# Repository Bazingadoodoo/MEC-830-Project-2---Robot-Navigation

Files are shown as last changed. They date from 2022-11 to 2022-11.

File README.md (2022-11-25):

# MEC-830-Project-2---Robot-Navigation

Group Member 

 - Nillan Nimal
 - Mohammed Khan
 - Cheng-Hao(Howard), Kao

 Arduino Board

 - pin 2: encoder left
 - pin 3: encoder right
 - pin 4: ultrasonic trig pin 
 - pin 5: ultrasonic echo pin
 - pin 6: servo signal pin (pwm) => X
 - pin 7: IR receiver pin => 11
 - pin 8: motor driver in3 => 7
 - pin 9: motor driver in4 => 8
 - pin 10: motor driver enB (pwm) => 6
 - pin 11: motor driver enA (pwm) => 9
 - pin 12: motor driver in1
 - pin 13: motor driver in2

enA: right wheel, in1, in2//
enB: left wheel, in3, in4//
caster wheel diameter: 2.56cm//
rubber wheel radius: 6.65cm//
distance = (impulses/20)*10.4558cm//

remote buttons:
-23971  25245   -7651
8925    765     -15811
-8161   -22441  -28561
26775   -26521  -20401 
12495   6375    31365
4335    14535   23205
17085   19125   21165

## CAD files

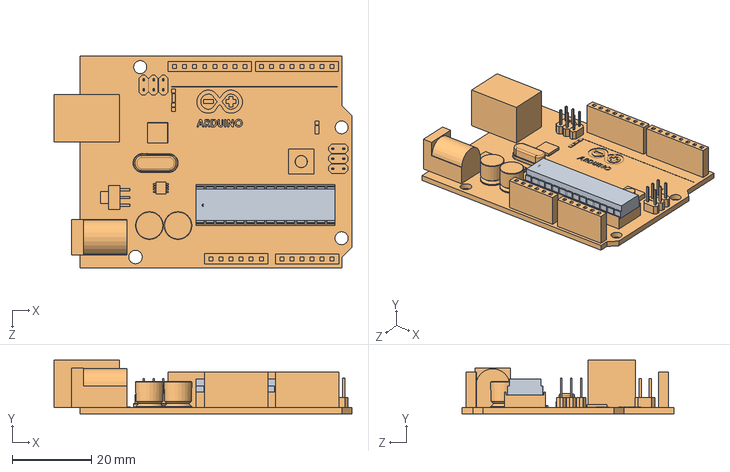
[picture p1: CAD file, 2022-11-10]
CAD Files/Arduino.SLDASM
75.1 x 13.6 x 53.5 mm
atmel
ARDUINO

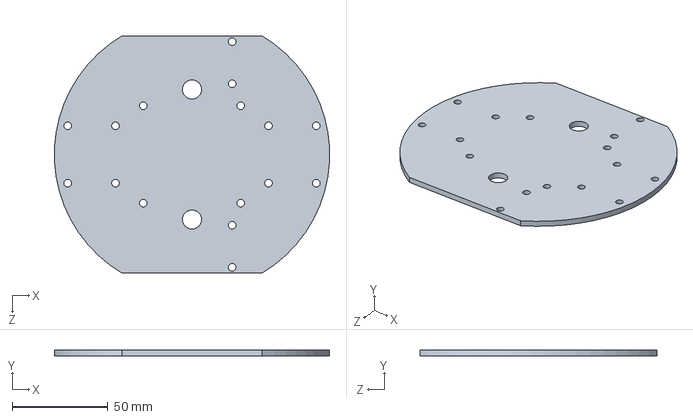
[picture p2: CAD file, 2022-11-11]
CAD Files/Lower Chassis.SLDPRT
143.8 x 3.00 x 124.0 mm

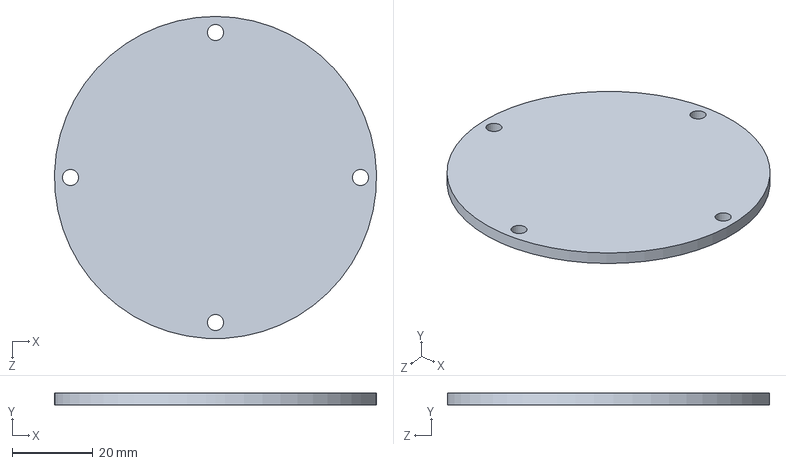
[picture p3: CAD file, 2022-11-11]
CAD Files/Upper Chassis.SLDPRT
80.0 x 3.00 x 80.0 mm

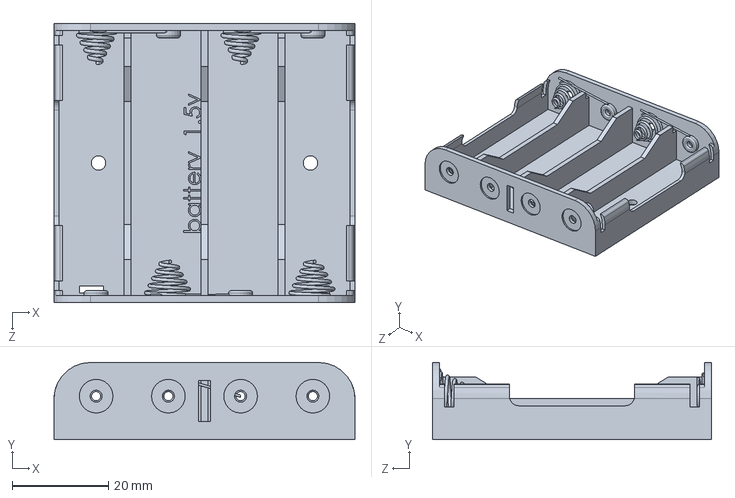
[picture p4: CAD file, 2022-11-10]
CAD Files/1.5V Battery Holder.SLDPRT
62.5 x 16.0 x 58.0 mm

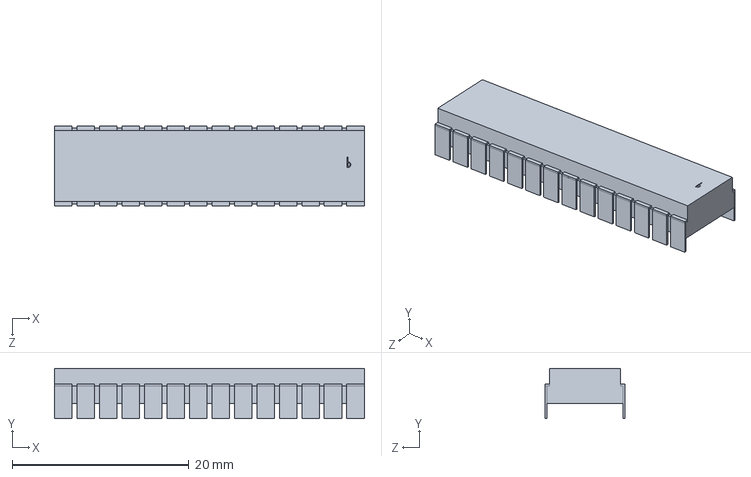
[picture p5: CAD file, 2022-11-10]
CAD Files/atmel.SLDPRT
35.0 x 5.70 x 9.00 mm

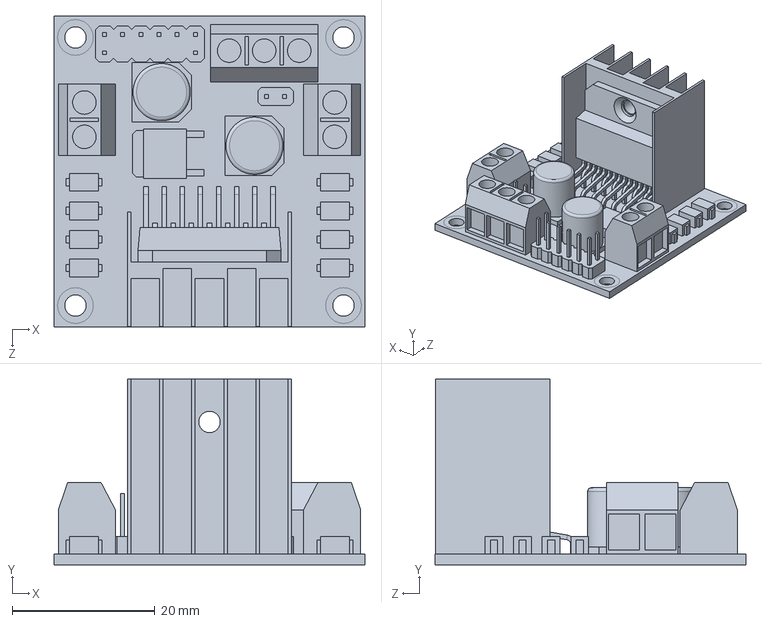
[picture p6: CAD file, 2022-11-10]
CAD Files/L298N Motor Driver arduino.SLDPRT
43.5 x 26.0 x 43.5 mm

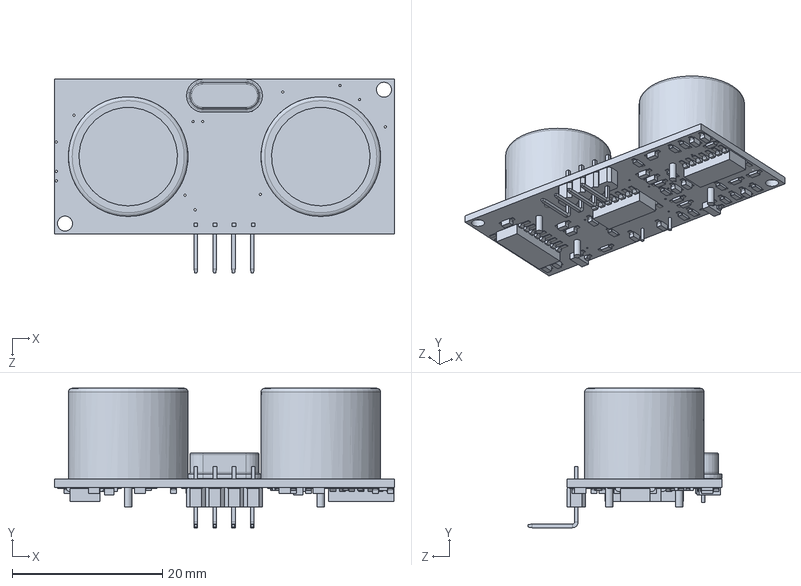
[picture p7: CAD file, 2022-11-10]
CAD Files/hc-sr04.SLDPRT
45.2 x 18.5 x 25.8 mm

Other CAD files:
CAD Files/ARDUINO.SLDPRT

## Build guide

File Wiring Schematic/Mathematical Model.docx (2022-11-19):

ϑ_m

1/((J_m +J_l )s^2 +cs)

r

+

Potentiometer

Motor

T_m

I_m

V_s

V_p

R_r

ϑ_r

K_e s

(R_(max))/(ϑ_(max))

I_p

K_t

1/(L_m s+R_m)

Microcontroller

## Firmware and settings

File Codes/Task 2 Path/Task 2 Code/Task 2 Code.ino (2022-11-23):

//IMU--------------------------------------
#include <Adafruit_Sensor.h>
#include <Adafruit_BNO055.h>
#include <utility/imumaths.h>
#include <Smoothed.h>
#include <Ewma.h>
#include <PID_v2.h>

Smoothed <float> average_rot_speedL;
Smoothed <float> average_rot_speedR;
Adafruit_BNO055 bno = Adafruit_BNO055(55);
float angle_offset;
double angle;
double angleR;

//path checkpoints
bool start = 1;
bool checkpoint_1 =0;
bool checkpoint_2 =0;
bool checkpoint_3 = 0;
bool rotateR = 1;

// ultrasonic sensor-----------------------
#define trigPin 4
#define echoPin 5
float distance; 

//Time variables
float previousTimeR = 0;
float currentTimeR = 0;
float previousTimeL = 0;
float currentTimeL = 0;
float loopTimeCurrent =0;
float loopTimePrevious =0;


// motor driver----------------------------
#define enA 9       // right wheel
#define enB 6       // left wheel
#define in1 12      // forward
#define in2 13      // backward
#define in3 7       // backward
#define in4 8       // forward

//Drive functions
float set_speed;

// PID Controller
double Kp_A = 8;
double Ki_A = 0.3;
double Kd_A = 0.4;
//8, 0.3, 0.4

double Kp_R = 2;
double Ki_R = 0.5;
double Kd_R = 0;
//2, 0.9, 0.0

double setpoint_rotate = 90.0;
double setpoint_drive = 1.0;
double output_rotate;
double output_drive;

//Proportional Control
int pControlSpeedR;
int pControlSpeedL;
int initialSpeed;
float targetAngle =0;
int maxSpeed = 255;
int minSpeed = 0;



PID myPID_drive(&angle,&output_drive,&setpoint_drive,Kp_A,Ki_A,Kd_A,DIRECT);
PID myPID_rotate(&angleR,&output_rotate,&setpoint_rotate,Kp_R,Ki_R,Kd_R,DIRECT);

void stop_car(void){
  setMotorL(0);
  setMotorR(0);
}

void drive_straight(double set_speed){
  myPID_drive.Compute();
  double rightSpeed = set_speed - output_drive;
  double leftSpeed = set_speed + output_drive;

  if (rightSpeed> 255){
    rightSpeed = 255;
  }
  else if (rightSpeed<0){
    rightSpeed = 0;
  }
  
  if (leftSpeed>255){
    leftSpeed = 255;
  }
  else if (leftSpeed<0){
    leftSpeed = 0;
  }

  setMotorR(rightSpeed);
  setMotorL(leftSpeed);
}

void SpeedControlF (int initialSpeed)                                                   // Speed Control Forward
{
  int currentAngle = measure_angle();

  pControlSpeedR = initialSpeed + (currentAngle - targetAngle)*kp;
  if (pControlSpeedR > maxSpeed)
  {
    pControlSpeedR = maxSpeed;
  }
  if (pControlSpeedR < minSpeed)
  {
    pControlSpeedR = minSpeed;
  }
  
  pControlSpeedL = initialSpeed - (currentAngle - targetAngle)*kp;
  if (pControlSpeedL > maxSpeed)
  {
    pControlSpeedL = maxSpeed;
  }
  if (pControlSpeedL < minSpeed)
  {
    pControlSpeedL = minSpeed;
  }

  setMotorR(pControlSpeedR);
  setMotorL(pControlSpeedL);
}

void rotate(){
  delay(1000);
  while (1){
    angleR = measure_angle();
    float error = abs(((angleR - setpoint_rotate)/(90.0))*100);
    myPID_rotate.Compute();
    double rightRotate = -output_rotate;
    double leftRotate = output_rotate;

    setMotorR(rightRotate);
    setMotorL(leftRotate);
    if (error<1)
      {
        stop_car();
        break;
      }
    }
  }


void setMotorR(int pwmR) {

  if (pwmR>0)
  {
    digitalWrite(in1, HIGH);
    digitalWrite(in2, LOW);
  }
  else if (pwmR<0){
    digitalWrite(in1, LOW);
    digitalWrite(in2, HIGH);
  }
  else if (pwmR ==0){
    digitalWrite(in1, LOW);
    digitalWrite(in2, LOW);
  }
  analogWrite(enA,abs(pwmR));
}

void setMotorL(int pwmL) {

  if (pwmL>0)
  {
    digitalWrite(in3, HIGH);
    digitalWrite(in4, LOW);
  }
  else if (pwmL<0){
    digitalWrite(in3, LOW);
    digitalWrite(in4, HIGH);
  }
  else if (pwmL ==0){
    digitalWrite(in3, LOW);
    digitalWrite(in4, LOW);
  }
  analogWrite(enB,abs(pwmL));
}


double measure_angle(void)
{
  double z_angle;// to determine absolute orientation 
  /* Get a new sensor event */ 
  sensors_event_t event; 
  bno.getEvent(&event);
  z_angle = event.orientation.x; //get z-axis rotation angle

  if (z_angle > 180){
    z_angle = z_angle - 360;
  }

  return z_angle;
}

float obstacle_detection(void)
{
  
  digitalWrite(trigPin, LOW);
  delayMicroseconds(2);
  digitalWrite(trigPin, HIGH);
  delayMicroseconds(10);
  digitalWrite(trigPin, LOW);
  float duration = pulseIn(echoPin, HIGH);
  float obstacle_distance = (duration * 0.034 / 2.0) * 1.0227 + 0.0031;
  return obstacle_distance;
  
}

void setup() {
  myPID_drive.SetMode(MANUAL); //initalize PID Controller
  myPID_drive.SetSampleTime(10);
  myPID_drive.SetOutputLimits(-200, 200);

  myPID_rotate.SetMode(MANUAL); //initalize PID Controller
  myPID_rotate.SetSampleTime(10);
  myPID_rotate.SetOutputLimits(-110, 110);

  //Initalize Ultrasonic Sensor
  pinMode(trigPin, OUTPUT);
  pinMode(echoPin,INPUT);

  Serial.begin(9600);
  Serial.println("Calibrating IMU");

  /* Initialise the sensor */
  if(!bno.begin())
  {
    /* There was a problem detecting the imu */
    Serial.print("no imu sensor detected");
    while(1);
  }
    delay(2000);
    bno.setExtCrystalUse(true);
    Serial.println("Done Calibrating");
    Serial.println("Starting...");
    sensors_event_t event; 
    bno.getEvent(&event);
}


void loop() {
  angle = measure_angle();
  if (start){
    myPID_drive.SetMode(AUTOMATIC);
    start = 0;
    checkpoint_1 =1;
  }

  if (checkpoint_1){
    distance = obstacle_detection();
    if (distance <= 22){
      myPID_drive.SetMode(MANUAL);
      stop_car();
      myPID_rotate.SetMode(AUTOMATIC);
      rotate();
      myPID_rotate.SetMode(MANUAL);
      checkpoint_1=0;
      checkpoint_2=1;
      setpoint_drive = 90.0;
      myPID_drive.SetMode(AUTOMATIC);
    }
    else
    { 
      drive_straight(120);
    }
  }

  if (checkpoint_2){
    distance = obstacle_detection();
    if (distance <= 22){
      myPID_drive.SetMode(MANUAL);
      stop_car();
      setpoint_rotate = 0.0;
      myPID_rotate.SetMode(AUTOMATIC);
      rotate();
      myPID_rotate.SetMode(MANUAL);
      checkpoint_2=0;
      checkpoint_3=1;
      setpoint_drive = 0.0;
      myPID_drive.SetMode(AUTOMATIC);
    }
    else
    { 
      SpeedControlF(120);
      //drive_straight(120);
    }
  }

  if (checkpoint_3){
    distance = obstacle_detection();
    if (distance <= 22){
      myPID_drive.SetMode(MANUAL);
      stop_car();
      setpoint_rotate = 0.0;
      myPID_rotate.SetMode(AUTOMATIC);
      rotate();
      myPID_rotate.SetMode(MANUAL);
      checkpoint_3 =0.0;
    }
    else
    {  SpeedControlF(120);
      //drive_straight(120);
    }
  }

}

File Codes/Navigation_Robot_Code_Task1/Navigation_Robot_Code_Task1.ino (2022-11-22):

//IMU--------------------------------------
#include <Adafruit_Sensor.h>
#include <Adafruit_BNO055.h>
#include <utility/imumaths.h>
Adafruit_BNO055 bno = Adafruit_BNO055(55);
float angle_offset;
float angle;
float angle_offset_mapped;

// encoder---------------------------------
#define leftEncoderPin 2
#define rightEncoderPin 3
float diskSlot = 20;
int leftCounter = 0;
int rightCounter = 0;
int Right = 0;
int Left = 0;

// ultrasonic sensor-----------------------
#define trigPin 4
#define echoPin 5

// servo motor-----------------------------
/*#include <Servo.h>
  #define servoPin 6
  Servo myservo;*/

// IR receiver-----------------------------
#include <IRremote.hpp>
#define irPin 11
IRrecv irReceive(irPin);
decode_results irInput;

// motor driver----------------------------
#define enA 9       // right wheel
#define enB 6       // left wheel
#define in1 12      // forward
#define in2 13      // backward
#define in3 7       // backward
#define in4 8       // forward

void ISR_Right() {
  if (Right) {
    rightCounter++;
  }
  else {
    rightCounter--;
  }
}

void ISR_Left() {
  if (Left) {
    leftCounter++;
  }
  else {
    leftCounter--;
  }
}

void RotateRight(int motorSpeedL, int motorSpeedR, float startAngle, float rotation_angle)
{
  float Z = measure_angle();
  float Z_mapped = Z + 180;
  if (Z_mapped >= 360)
  {
    Z_mapped = Z_mapped - 360;
  }
  while ((Z_mapped - startAngle) < 90)
  {
    digitalWrite(in1, HIGH);
    digitalWrite(in2, LOW);
    digitalWrite(in3, HIGH);
    digitalWrite(in4, LOW);
    analogWrite(enA, motorSpeedR);
    analogWrite(enB, motorSpeedL);
    //-----------------------------------------------------------------
    float Z = measure_angle();      // when updating Z_mapped this way,
    float Z_mapped = Z + 180;       // the while loop cannot properly 
    if (Z_mapped >= 360)            // determine when to execute and 
    {                               // when to stop
      Z_mapped = Z_mapped - 360;    
    }                               
    //-----------------------------------------------------------------
    //Z_mapped++;                   // when updating Z_mapped this way,
                                    // the while loop functions normally
    //-----------------------------------------------------------------
    Serial.print("Z_mapped: ");
    Serial.print(Z_mapped);
    Serial.print("        //  ");
    Serial.print("startAngle: ");
    Serial.println(startAngle);
    Serial.print("rotation_angle: ");
    Serial.print(rotation_angle);
    Serial.print("  //  ");
    Serial.print("Angle Difference: ");
    Serial.println(Z_mapped - startAngle);
    delay(100);
  }
  if ((Z_mapped - startAngle) >= rotation_angle)
  {
    TurnOff();
    Serial.println("off");
  }
}

void TurnRight(int motorSpeedL, int motorSpeedR, double delayTime) {
  Right = 1;
  Left = 0;
  digitalWrite(in1, HIGH);
  digitalWrite(in2, LOW);
  digitalWrite(in3, HIGH);
  digitalWrite(in4, LOW);
  analogWrite(enA, motorSpeedR);
  analogWrite(enB, motorSpeedL);
  delay(delayTime);
  TurnOff();
}

void TurnLeft(int motorSpeedL, int motorSpeedR, double delayTime) {
  Right = 0;
  Left = 1;
  digitalWrite(in1, LOW);
  digitalWrite(in2, HIGH);
  digitalWrite(in3, LOW);
  digitalWrite(in4, HIGH);
  analogWrite(enA, motorSpeedR);
  analogWrite(enB, motorSpeedL);
  delay(delayTime);
  TurnOff();
}

void DriveForward(int motorSpeedL, int motorSpeedR, double delayTime) {
  Right = 1;
  Left = 1;
  digitalWrite(in1, LOW);
  digitalWrite(in2, HIGH);
  digitalWrite(in3, HIGH);
  digitalWrite(in4, LOW);
  analogWrite(enA, motorSpeedR);
  analogWrite(enB, motorSpeedL);
  delay(delayTime);
  TurnOff();
}

void DriveBackward(int motorSpeedL, int motorSpeedR, double delayTime) {
  Right = 0;
  Left = 0;
  digitalWrite(in1, HIGH);
  digitalWrite(in2, LOW);
  digitalWrite(in3, LOW);
  digitalWrite(in4, HIGH);
  analogWrite(enA, motorSpeedR);
  analogWrite(enB, motorSpeedL);
  delay(delayTime);
  TurnOff();
}

void TurnOff() {
  Right = 0;
  Left = 0;
  digitalWrite(in1, LOW);
  digitalWrite(in2, LOW);
  digitalWrite(in3, LOW);
  digitalWrite(in4, LOW);
}

float measure_angle(void)
{
  float z_angle;// to determine absolute orientation
  /* Get a new sensor event */
  sensors_event_t event;
  bno.getEvent(&event);
  z_angle = event.orientation.x; //get z-axis rotation angle
  //Serial.println(z_angle);
  return z_angle;
}

void Odometry(float offsetR, float offsetL) {
  float R = 0.03325;
  float SR = ((rightCounter - offsetR) / 20) * (2 * PI * R);
  float SL = ((leftCounter - offsetL) / 20) * (2 * PI * R);
  float meanDistance = (SR + SL) / 2;
  return meanDistance;
}

void setup()
{
  Serial.begin(9600);
  attachInterrupt(digitalPinToInterrupt(leftEncoderPin), ISR_Left, RISING);
  attachInterrupt(digitalPinToInterrupt(rightEncoderPin), ISR_Right, RISING);
  irReceive.enableIRIn();
  Serial.println();
  Serial.println("Calibrating IMU");

  /* Initialise the sensor */
  if (!bno.begin())
  {
    /* There was a problem detecting the imu */

    Serial.print("no imu sensor detected");
    while (1);
  }
  delay(2000);
  bno.setExtCrystalUse(true);
  Serial.println("Done Calibrating");
  Serial.println("Starting...");
  sensors_event_t event;
  bno.getEvent(&event);
  angle_offset = event.orientation.x; //get z-axis rotation angle
  angle_offset_mapped = angle_offset + 180;
  if (angle_offset_mapped > 360)
  {
    angle_offset_mapped = angle_offset_mapped - 360;
  }
  Serial.print("Offset: ");
  Serial.println(angle_offset_mapped);
}

void loop()
{
  if (irReceive.decode(&irInput))
  {
    int irReading = irInput.value;
    switch (irReading)
    {
      case 6375:                // button 2
        DriveForward(123, 100, 1000);
        break;
      case 19125:               // button 8
        DriveBackward(113, 95, 1000);
        break;
      case 4335:                // button 4
        break;
      case 23205:               // button 6
        RotateRight(100, 71, angle_offset_mapped, 90);
        break;
      case 14535:               // button 5
        TurnOff();
        break;
      case 12495:               // button 1
        TurnLeft(0, 100, 300);
        break;
      case 31365:               // button 3
        TurnRight(120, 0, 300);
        break;
    }
    irReceive.resume();
    //Serial.println(irReading);
  }
  /*
    Serial.print("left counter: ");
    Serial.print(leftCounter);
    Serial.print("  //  ");
    Serial.print("right counter: ");
    Serial.println(rightCounter);
  */
}

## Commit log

2022-11-10 CAD Models
    This includes CAD models of parts that will be used and 3D printed to build the robot. There will be more updates.
    [1.5V Battery Holder.SLDPRT, ARDUINO.SLDPRT, Arduino.SLDASM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]
2022-11-10 CAD Folder
    Added a new folder to organize things for future use
    [1.5V Battery Holder.SLDPRT, ARDUINO.SLDPRT, Arduino.SLDASM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]
2022-11-11 Chassis CAD Update
    [Lower Chassis.SLDPRT, Upper Chassis.SLDPRT]
2022-11-14 Robot Circuit Connections
    The robot has actually been built with all connections made. Pins have been recorded and actual coding starts next week
2022-11-19 Update README.md
    It was noticed by the team that an IMU is not ideal due to possible drifting errors. Current solution is to adopt a optical encoder instead.
2022-11-19 Interrupt Included
    Interrupt functions have been included for determining wheel speed. Also, some notes have been added to the readme file just for the team as reminders
2022-11-19 Wiring Schematic, Code Change, Mathematical Model, and File Relocation
    [Wiring Schematic.kicad_pcb, Wiring Schematic.kicad_sch]
2022-11-19 Serial Display
    Forgot to initialize serial monitor at first. Fixed
    [Navigation_Robot_Code_Temlpate.ino]
2022-11-19 File Relocation
    [Wiring Schematic.kicad_sch]
2022-11-20 Template expansion
    Included IMUs
2022-11-20 Template Expansion
    Included IMU's. Previous expansion was done on the wrong file
    [Navigation_Robot_Code_Temlpate.ino]
2022-11-20 Fixing
    The board was damaged and the team had to change pins for different components. More will be done to determine the best solution.
    [Navigation_Robot_Code_Task1.ino]
2022-11-20 IR Remote
    Values the system reads when buttons on the IR remote are pushed
2022-11-20 Pin Change
    Some pins of the board were broken, and thus the codes had to be changed
    [Navigation_Robot_Code_Task1.ino, Navigation_Robot_Code_Temlpate.ino]
2022-11-20 Direction detection
    Now the encoder takes account of the direction of the car
2022-11-20 Trials and errors for motors
    [Navigation_Robot_Code_Task1.ino, Navigation_Robot_Code_Temlpate.ino]
2022-11-20 Error Correction
    Error in codes. fixed
    [Navigation_Robot_Code_Task1.ino, Navigation_Robot_Code_Temlpate.ino]
2022-11-21 Odometry Function
2022-11-21 Task 1 and Task 3
    Task 1 is done except more testing is needed and incorporation of IMU (currently not functioning). 1st version of Task 3 has also been completed and will be improved upon.
2022-11-22 Issue Encountered
    This problem could not be resolved and has been commented in the codes. Will discuss with the team after to see if it can be resolved.
    [Navigation_Robot_Code_Task1.ino]
2022-11-23 Tuned Task 2 Code with Updated PID values
2022-11-25 Schematic and Task 1 Update
    [Wiring Schematic.fzz, Wiring Schematic.kicad_pcb, Wiring Schematic.kicad_sch]
